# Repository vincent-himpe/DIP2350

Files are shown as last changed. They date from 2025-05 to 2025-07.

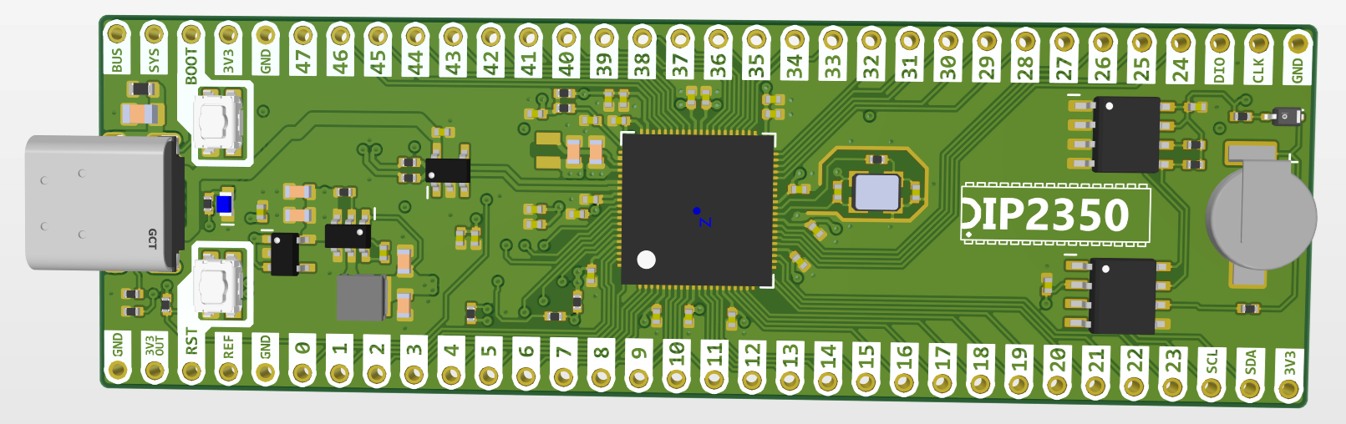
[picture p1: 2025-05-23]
IMAGES/DIP2350-RC2-FRONT.png

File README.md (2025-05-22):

# DIP2350
## An RP2350 Packaged as a 64 pin DIP package that fits a standard 64pin dip socket (motorola MC68000 style)

### Overview

- USB Type-C connector. Right angle , thru hole for mechanical stability. long overhang so you can have this go through an enclosure wall
- USB powered or self powered. self powered up to 12 volt
- ideal diode / or-ing / e-fuse circuit (optional) to prevent backfeeding usb. Current limit on the ideal diode. the circuit can be used as a power or-ing to provide backup power from a Li-Ion cell and charger
- ESD protection on the USB port using TVS diodes
- 3v3 DC/Dc regulator can deliver up to 1A of load current. In this case you need to provide 5v as USB cannot provide source current.
- RP2350B in 80 pin QFN with all 48 GPIO brought out.
- Flash 128Mbit
- optional PSRAM on GPIO47
- optional 3v reference for analog circuitry LM4040-3
- Heartbeat led on gp25 with solder bridge. Can be removed from circuit.
- using abracon XTAL and polarized inductor for 1v1 regulator
- boot and reset button. secondary boot button under usb so you can use a paperclip through the enclosure to force boot.
- on board, optional i2c bus :
- - I2C EEPROM or FRAM
  - I2C RTC with battery backup 1220 cell.
  - - cheap version using an M41t11
    - precision using a MEMS DS3231. option to use brown-out detection to hold cpu in reset till power stabilizes. optional interrupt on GPIO21. User needs to wire the i2c bus to desired io port.
- 4 layer board with controlled impedance and power planes. Board designed so it can be made at OshPark, JLCPCB or PCBway
- CAD source available under Creative Commons ZERO . Public Domain License. Altium Format. 
- Production pack (gerber/drill/bom available.
- BOM is procurable from Digikey/Mouser as well as LCSC (Asia) with direct LCSC order codes if you want his to be partially assembled by JLCPCB.
- pinheaders to be used are the turned pin type. Not the square Dupont style that destroys breadboards and ic sockets. Preci-Dip or equivalent.

DIP2350 FRONT

DIP2350 BACK

## Schematic

[DIP2350 SCHEMATIC - RC0.pdf](https://github.com/user-attachments/files/20359181/DIP2350.SCHEMATIC.-.RC0.pdf)

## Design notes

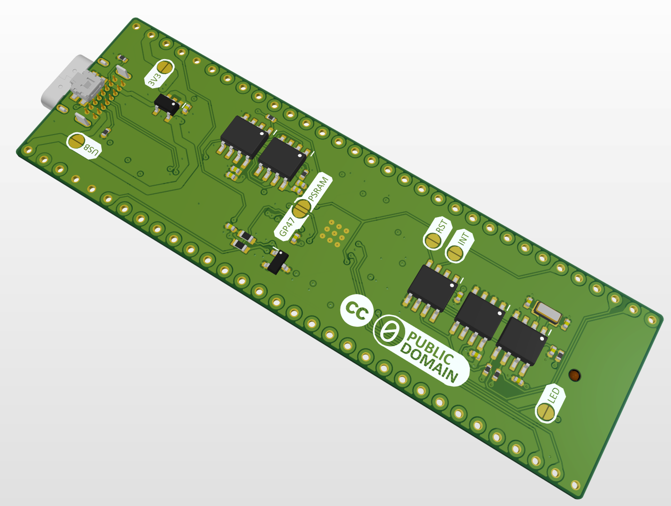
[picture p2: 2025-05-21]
IMAGES/DIP2350-BACK.png

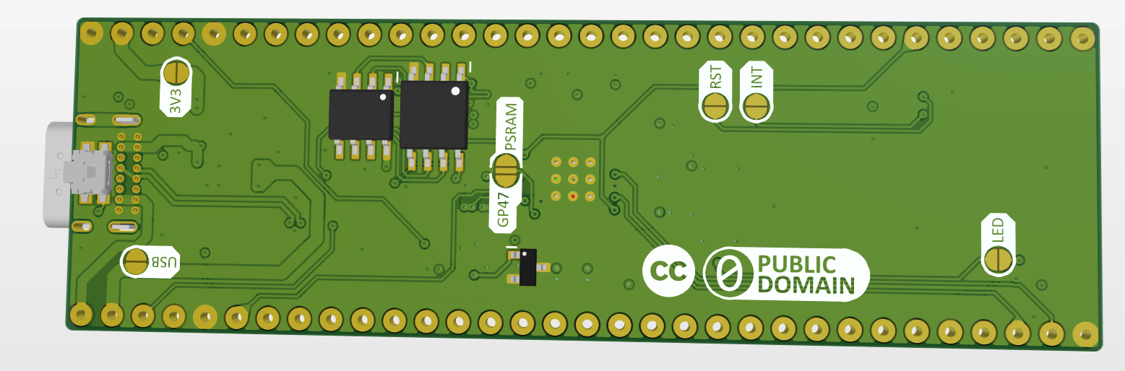
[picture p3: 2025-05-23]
IMAGES/DIP2350-RC2-BACK.png

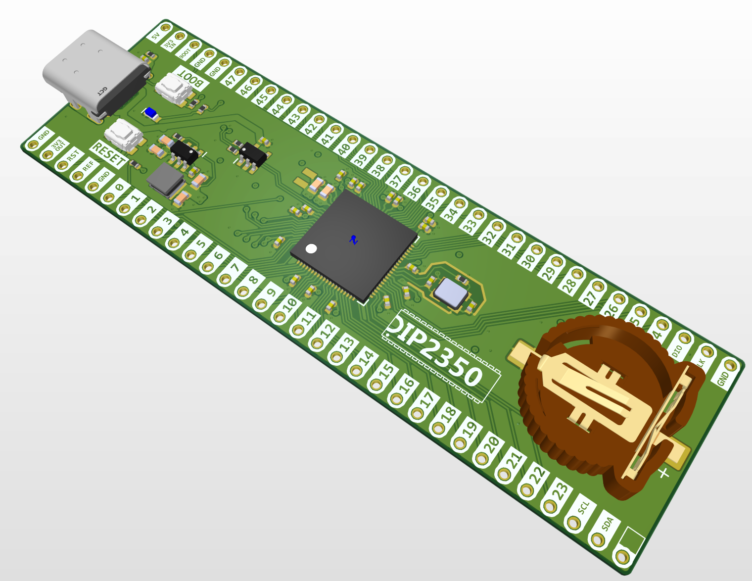
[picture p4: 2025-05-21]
IMAGES/DIP2350-FRONT.png

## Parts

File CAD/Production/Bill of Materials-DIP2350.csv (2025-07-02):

Description | Designator | Quantity | LCSC
CAPACITOR,CERAMIC,22uF,16V,X5R,0603 | C1, C2, C4, C5 | 4 | C2762594
CAPACITOR,CERAMIC,100nF,16V,X7R,0402 | C3, C6, C7, C8, C9, C10, C12, C13, C14, C15, C16, C18, C20, C22, C27, C28, C32, C34, C35, C39 | 20 | C60474
CAPACITOR,CERAMIC,4u7,10V,X5R,0402, CAPACITOR,CERAMIC,4u7,10V,X5R,0603 | C11, C17, C19, C21, C23, C24, C29, C30, C31, C40 | 10 | C1705
CAPACITOR,CERAMIC,15pF,50V,C0G,0402 | C25, C26 | 2 | C3906764
CAPACITOR,CERAMIC,10nF,200V,X7R,0805 (2012),ESD | C33 | 1 | C36911368
DIODE,TVS,DUAL,UNIDIRECTIONAL,USB | D1 | 1 | C22358704
LED,BLUE,0603 | D2 | 1 | C965807
DIODE,75V,215mA,SOD323,LOW LEAKAGE | D3, D4 | 2 | C459842
CONN,USB-C,16P,RA,TH,8.94X9.17 | J1 | 1 | C36936564
CONN,1X3,1MM,RA,SMD,JST,SM03B | J7 | 1 | C160403
BAT,3V,SMD,SEIKO MS621R | K1 | 1
IND,4.7uH,1.06A,3X3, NRH3012T4R7MN | L1 | 1 | C5159666
IND,3U3,RP2350, ABRACON AOTA-B201610S3R3-101-T | L2 | 1 | C42411119
RESISTOR,1K,1%,63mW,0402 (1005) | R1, R6, R7, R10, R17, R18, R19 | 7 | C106235
RESISTOR,5K1,1%,63mW,0402 (1005) | R2, R3 | 2 | C105872
RESISTOR,27R,1%,63mW,0402 (1005) | R4, R5 | 2 | C138021
RESISTOR,10K,1%,63mW,0402 (1005) | R8, R9, R14 | 3 | C60490
RESISTOR,33R,1%,63mW,0402 (1005) | R11, R16 | 2 | C138002
RESISTOR,4K7,1%,63mW,0402 (1005) | R12, R13 | 2 | C105871
RESISTOR,1M,1%,100mW,0603 (1608) | R15 | 1 | C105578
SW,SMD,TACT,4PIN,2.9X3.5,4PIN,SIDE ACTUATOR | SW1 | 1 | C483790
SW,SMD,TACT,4PIN,2.9X3.5,4PIN | SW2, SW3 | 2 | C483888
IC,CPU,RP2350B,QFN80 | U1 | 1 | C42415655
IC,PMIC,STEP-DOWN, 2A 3.3V | U2 | 1 | C780769
IC,FLASH,QSPI,16Mx8 | U3 | 1 | C97521
IC,VOLTAGE REFERENCE,3.0V | U4 | 1 | C460608
IC,PSRAM,QSPI,8Mx8,SO8 | U5 | 1 | C5333729
IC,FRAM,I2C, 64KBIT | U6 | 1 | C914923
IC,RTC,I2C,DS3231M | U8 | 1 | C107410
IC,PMIC,IDEAL DIODE ORING CONTROLLER | U9 | 1 | C3235547
XTAL,12MHZ,RP2350 | X1 | 1 | C20625731

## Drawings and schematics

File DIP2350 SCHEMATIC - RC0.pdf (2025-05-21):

R2 | 0402
R10 | 0402

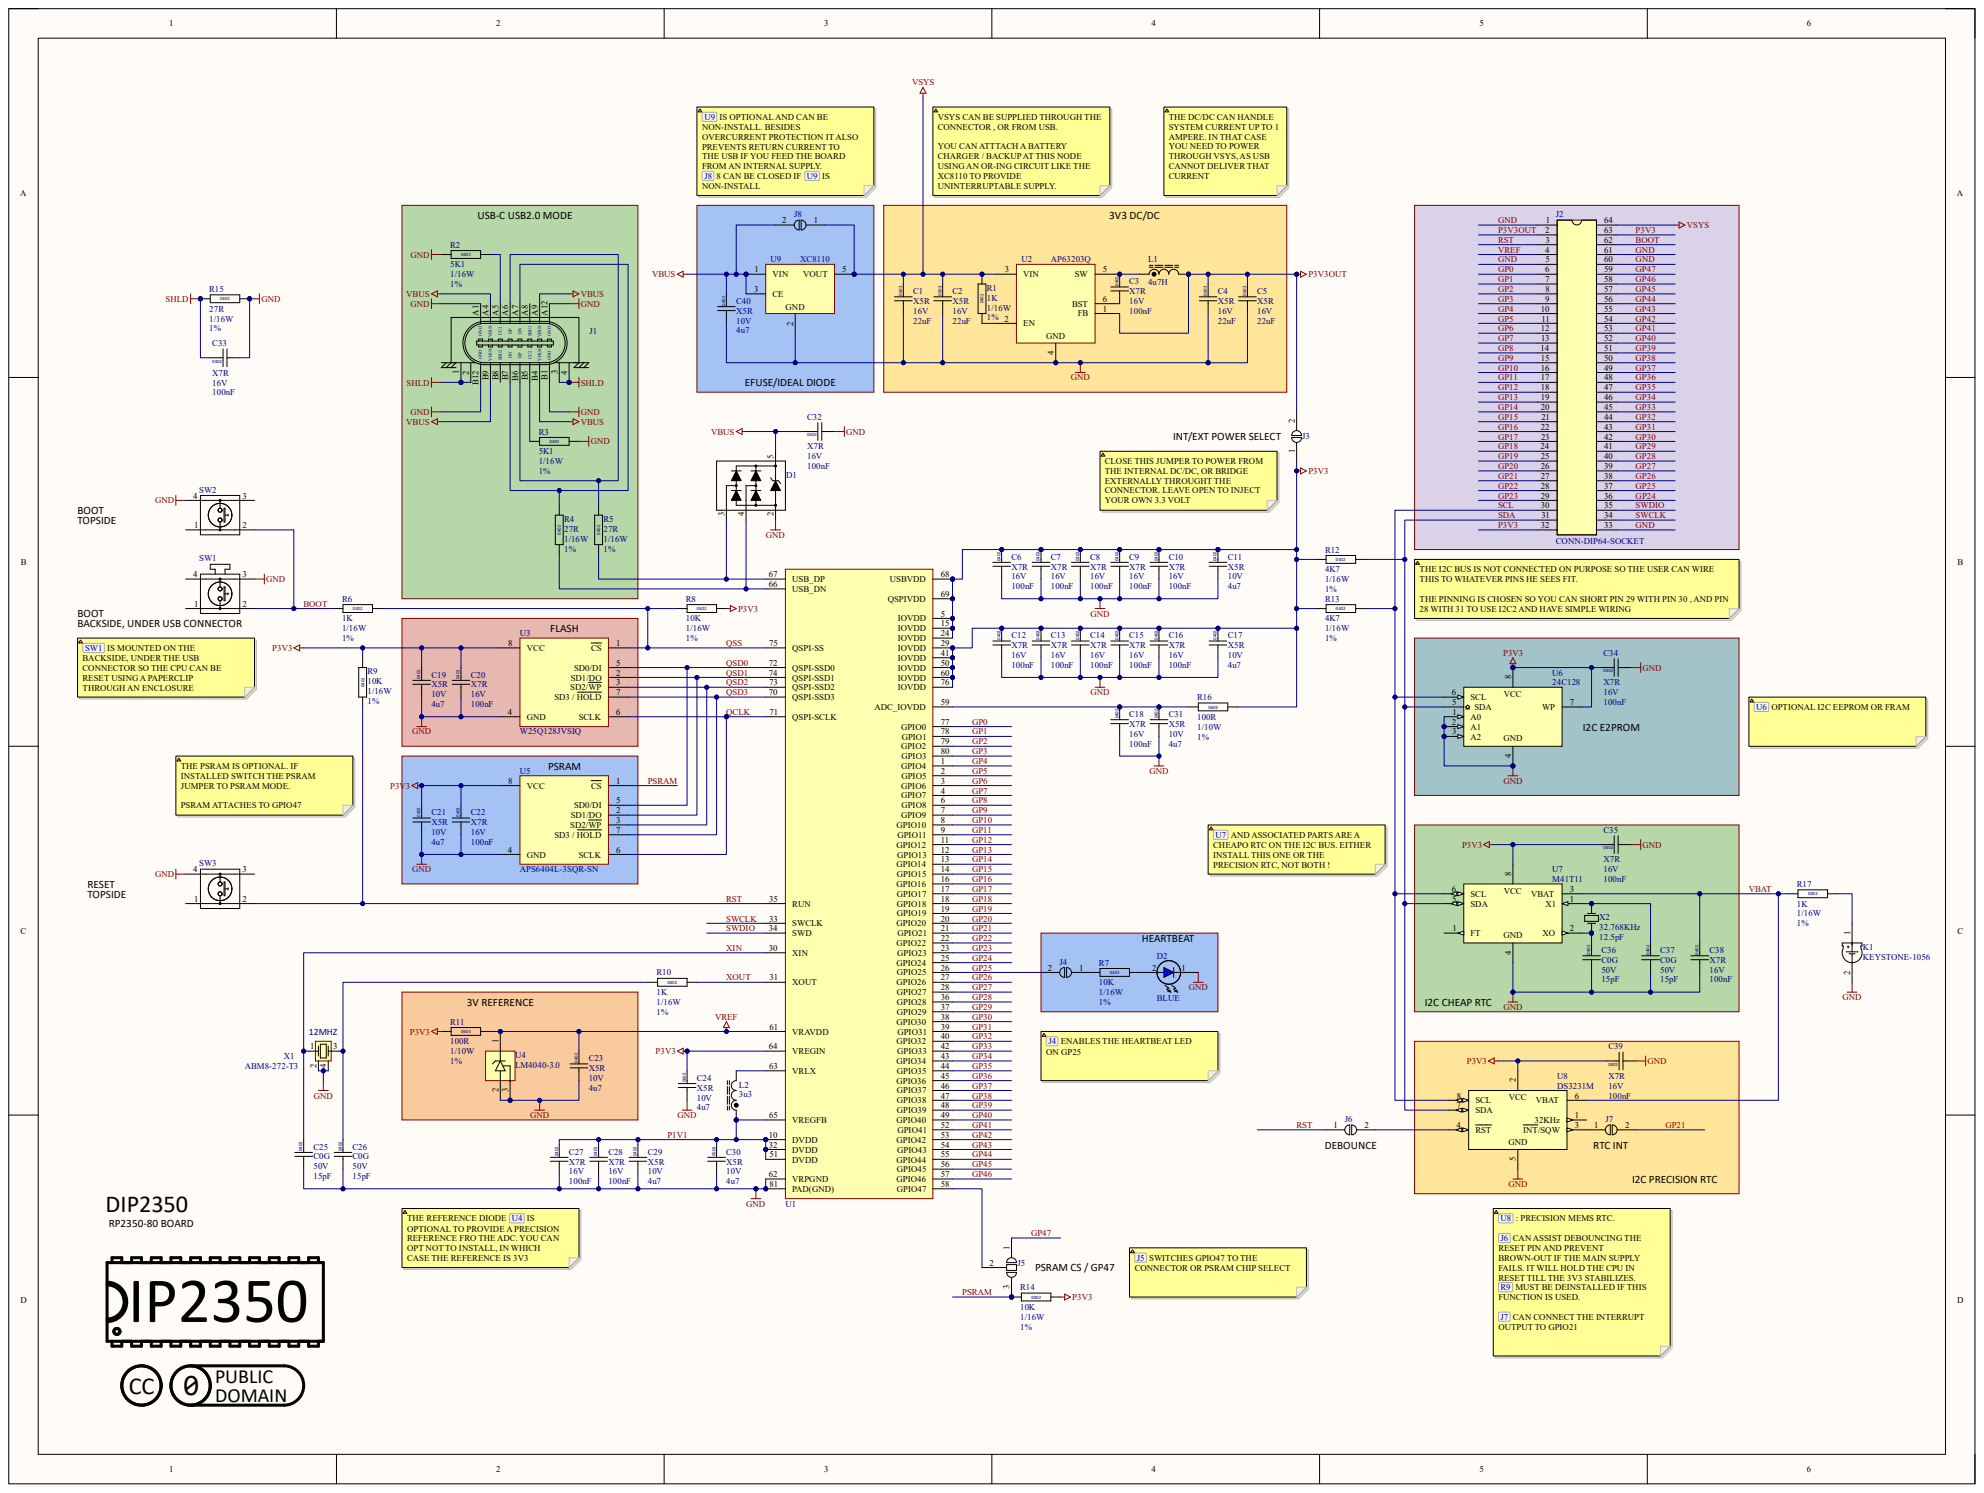
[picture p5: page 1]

U9 IS OPTIONAL AND CAN BE
NON-INSTALL. BESIDES
OVERCURRENT PROTECTION IT ALSO
PREVENTS RETURN CURRENT TO
THE USB IF YOU FEED THE BOARD
FROM AN INTERNAL SUPPLY.
J8 8 CAN BE CLOSED IF U9 IS
NON-INSTALL

VSYS CAN BE SUPPLIED THROUGH THE
CONNECTOR , OR FROM USB.

THE DC/DC CAN HANDLE
SYSTEM CURRENT UP TO 1
AMPERE. IN THAT CASE
YOU NEED TO POWER
THROUGH VSYS, AS USB
CANNOT DELIVER THAT
CURRENT

YOU CAN ATTTACH A BATTERY
CHARGER / BACKUP AT THIS NODE
USING AN OR-ING CIRCUIT LIKE THE
XC8110 TO PROVIDE
UNINTERRUPTABLE SUPPLY.

INT/EXT POWER SELECT

CLOSE THIS JUMPER TO POWER FROM
THE INTERNAL DC/DC, OR BRIDGE
EXTERNALLY THROUGHT THE
CONNECTOR. LEAVE OPEN TO INJECT
YOUR OWN 3.3 VOLT

THE I2C BUS IS NOT CONNECTED ON PURPOSE SO THE USER CAN WIRE
THIS TO WHATEVER PINS HE SEES FIT.

BOOT
BACKSIDE, UNDER USB CONNECTOR

THE PINNING IS CHOSEN SO YOU CAN SHORT PIN 29 WITH PIN 30 , AND PIN
28 WITH 31 TO USE I2C2 AND HAVE SIMPLE WIRING

SW1 IS MOUNTED ON THE
BACKSIDE, UNDER THE USB
CONNECTOR SO THE CPU CAN BE
RESET USING A PAPERCLIP
THROUGH AN ENCLOSURE

U6 OPTIONAL I2C EEPROM OR FRAM

THE PSRAM IS OPTIONAL. IF
INSTALLED SWITCH THE PSRAM
JUMPER TO PSRAM MODE.

U7 AND ASSOCIATED PARTS ARE A
CHEAPO RTC ON THE I2C BUS. EITHER
INSTALL THIS ONE OR THE
PRECISION RTC, NOT BOTH !

J4 ENABLES THE HEARTBEAT LED

THE REFERENCE DIODE U4 IS
OPTIONAL TO PROVIDE A PRECISION
REFERENCE FRO THE ADC. YOU CAN
OPT NOT TO INSTALL, IN WHICH
CASE THE REFERENCE IS 3V3

J6 CAN ASSIST DEBOUNCING THE
RESET PIN AND PREVENT
BROWN-OUT IF THE MAIN SUPPLY
FAILS. IT WILL HOLD THE CPU IN
RESET TILL THE 3V3 STABILIZES.
R9 MUST BE DEINSTALLED IF THIS
FUNCTION IS USED.

J5 SWITCHES GPIO47 TO THE
CONNECTOR OR PSRAM CHIP SELECT

J7 CAN CONNECT THE INTERRUPT
OUTPUT TO GPIO21

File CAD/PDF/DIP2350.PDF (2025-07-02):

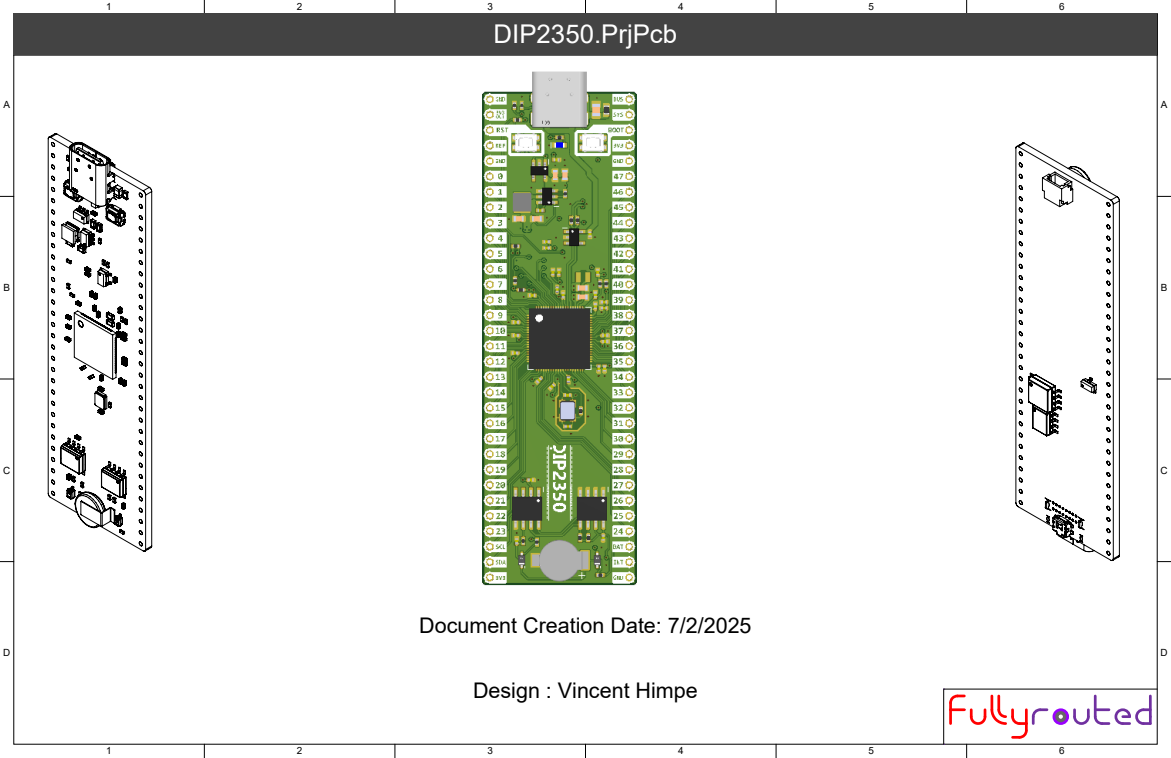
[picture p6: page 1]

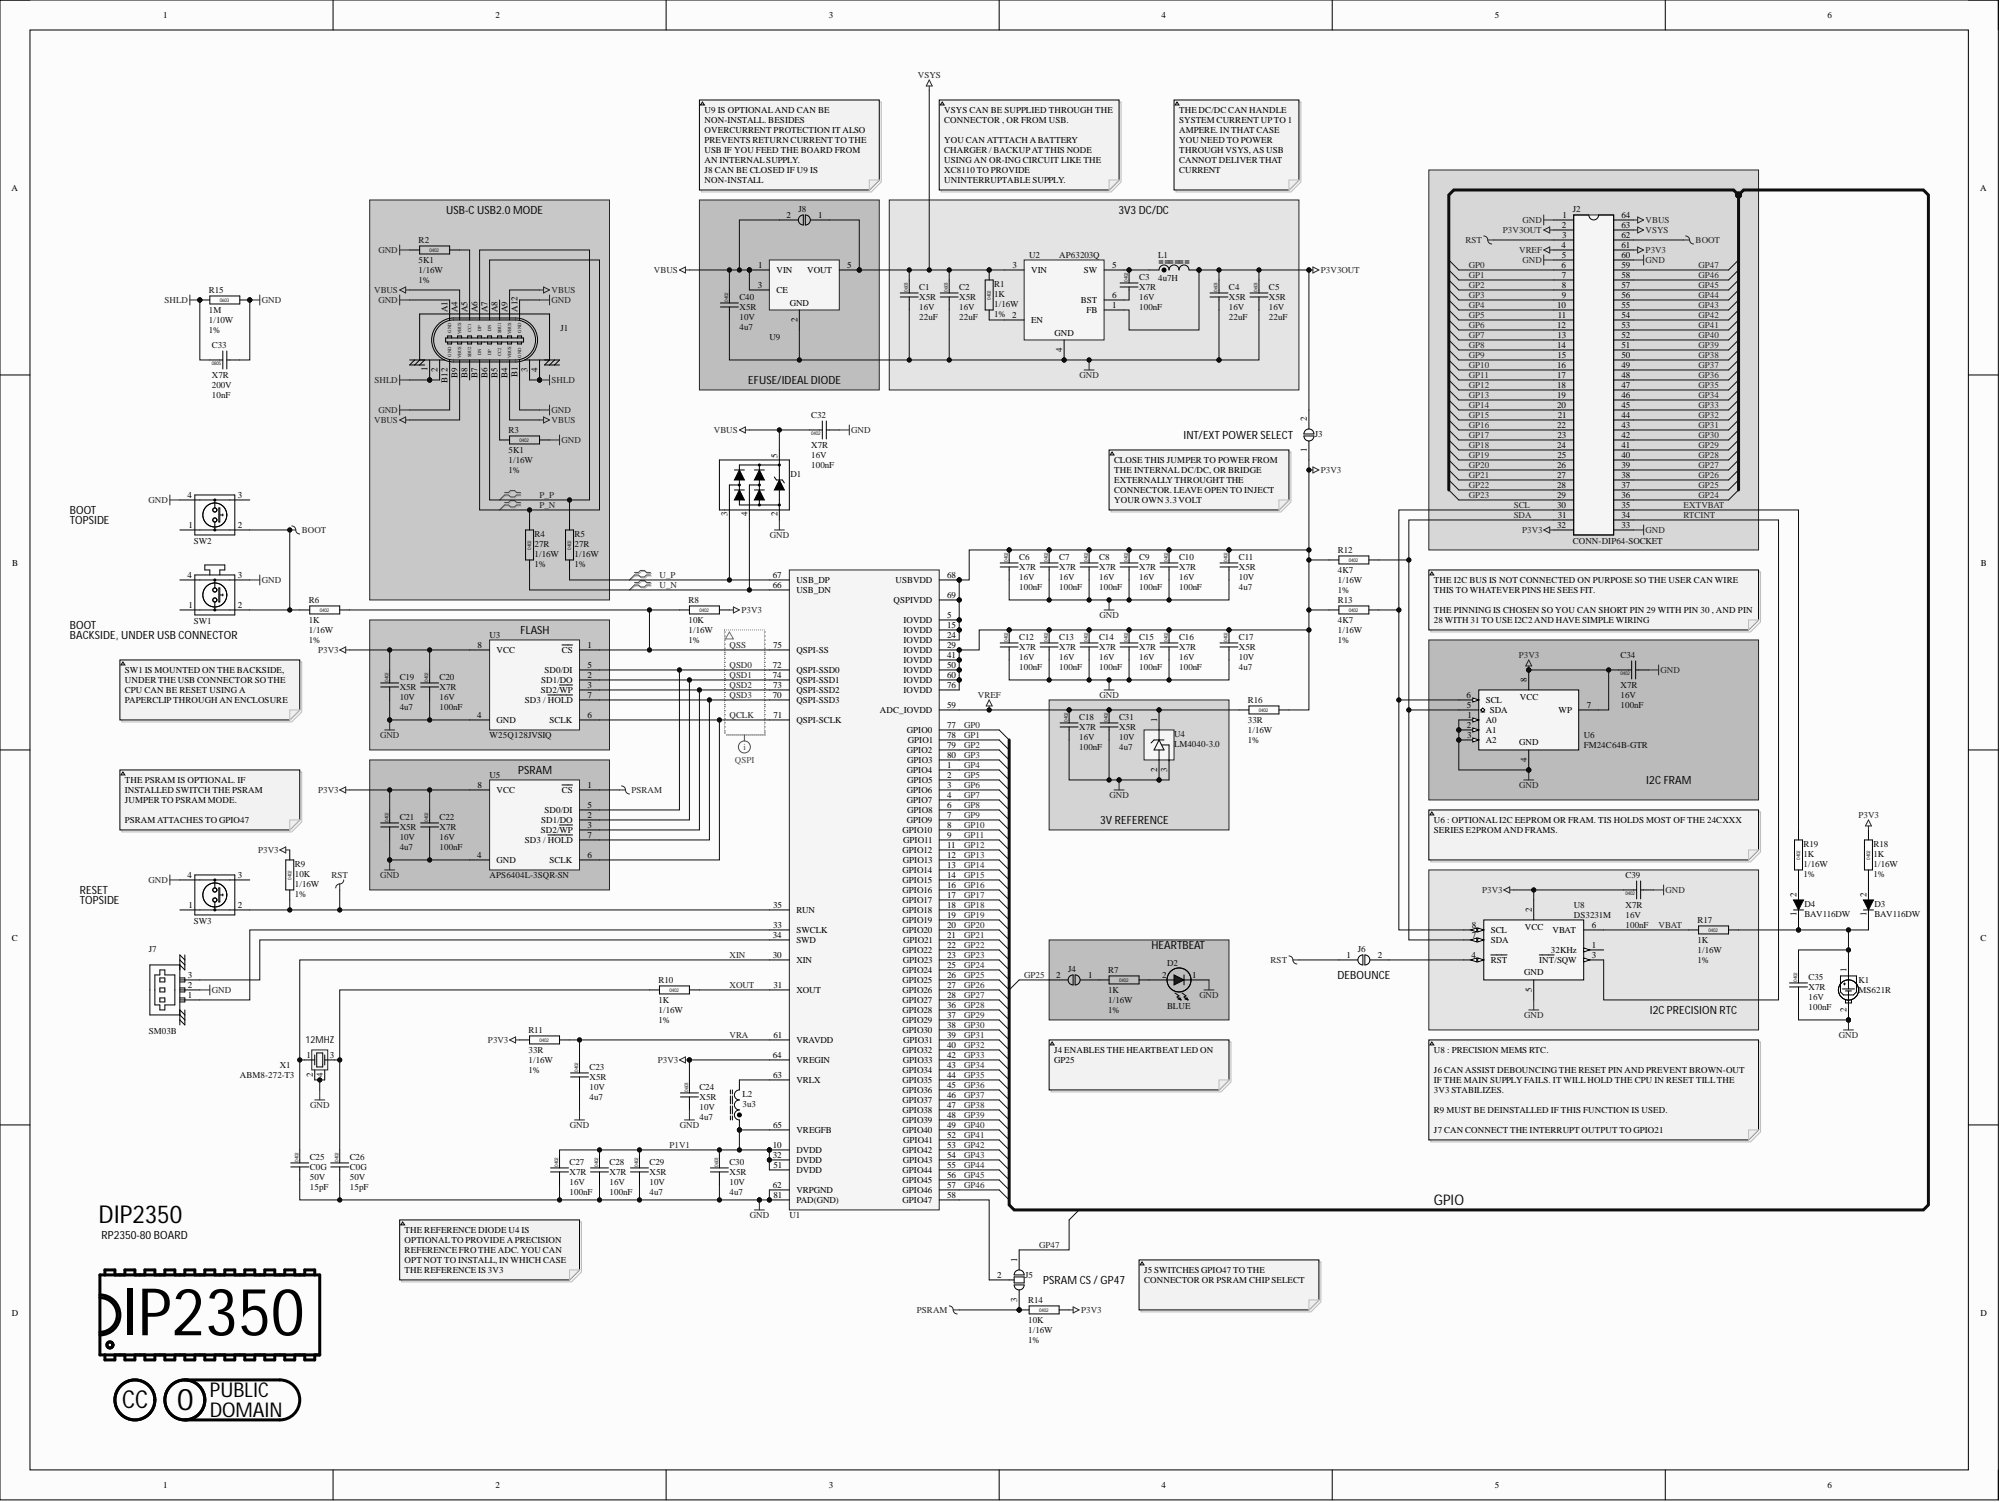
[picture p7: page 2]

3 | QSD 2 | 7 3 | | 7 6 | G N
7 | | QSD 3 | 7 0

3 | 8 0
7 | 9 GP1 1
6 | 1 1 GP1 2

1 0
3 2

OR PSRAM CHIP SE

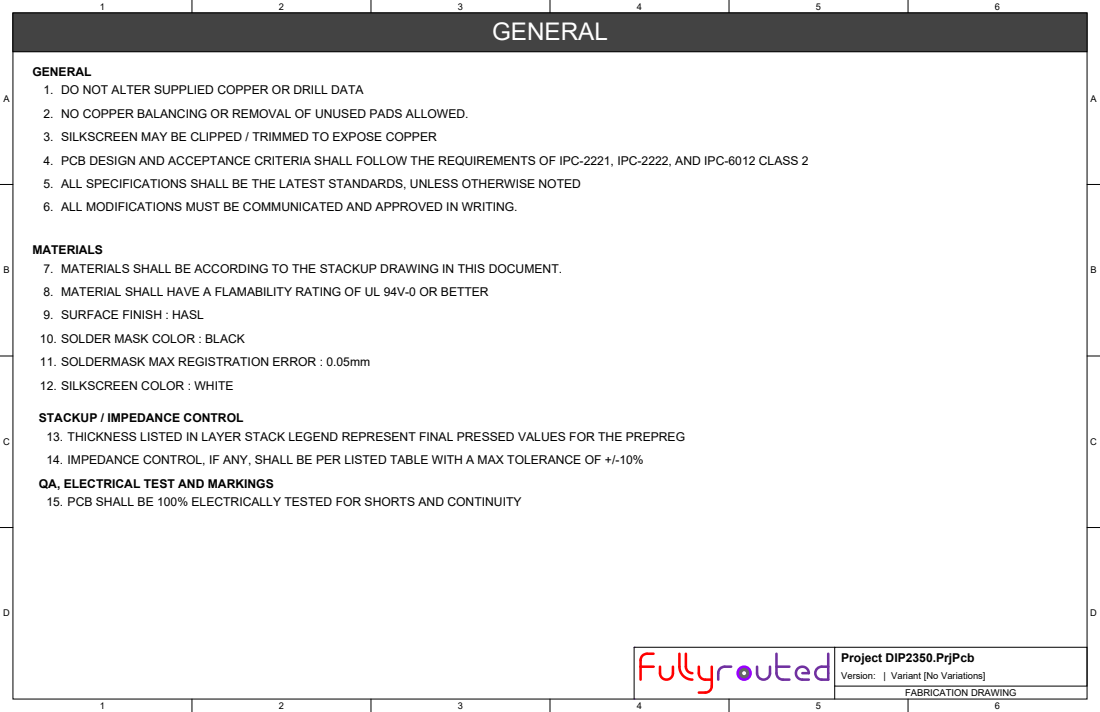
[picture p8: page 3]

GENERAL
1. DO NOT ALTER SUPPLIED COPPER OR DRILL DATA
2. NO COPPER BALANCING OR REMOVAL OF UNUSED PADS ALLOWED.
3. SILKSCREEN MAY BE CLIPPED / TRIMMED TO EXPOSE COPPER
4. PCB DESIGN AND ACCEPTANCE CRITERIA SHALL FOLLOW THE REQUIREMENTS OF IPC-2221, IPC-2222, AND IPC-6012 CLASS 2
5. ALL SPECIFICATIONS SHALL BE THE LATEST STANDARDS, UNLESS OTHERWISE NOTED
6. ALL MODIFICATIONS MUST BE COMMUNICATED AND APPROVED IN WRITING.

MATERIALS
7. MATERIALS SHALL BE ACCORDING TO THE STACKUP DRAWING IN THIS DOCUMENT.
8. MATERIAL SHALL HAVE A FLAMABILITY RATING OF UL 94V-0 OR BETTER
9. SURFACE FINISH : HASL
10. SOLDER MASK COLOR : BLACK
11. SOLDERMASK MAX REGISTRATION ERROR : 0.05mm
12. SILKSCREEN COLOR : WHITE

STACKUP / IMPEDANCE CONTROL
13. THICKNESS LISTED IN LAYER STACK LEGEND REPRESENT FINAL PRESSED VALUES FOR THE PREPREG
14. IMPEDANCE CONTROL, IF ANY, SHALL BE PER LISTED TABLE WITH A MAX TOLERANCE OF +/-10%
QA, ELECTRICAL TEST AND MARKINGS
15. PCB SHALL BE 100% ELECTRICALLY TESTED FOR SHORTS AND CONTINUITY

Project DIP2350.PrjPcb
Version: | Variant [No Variations]

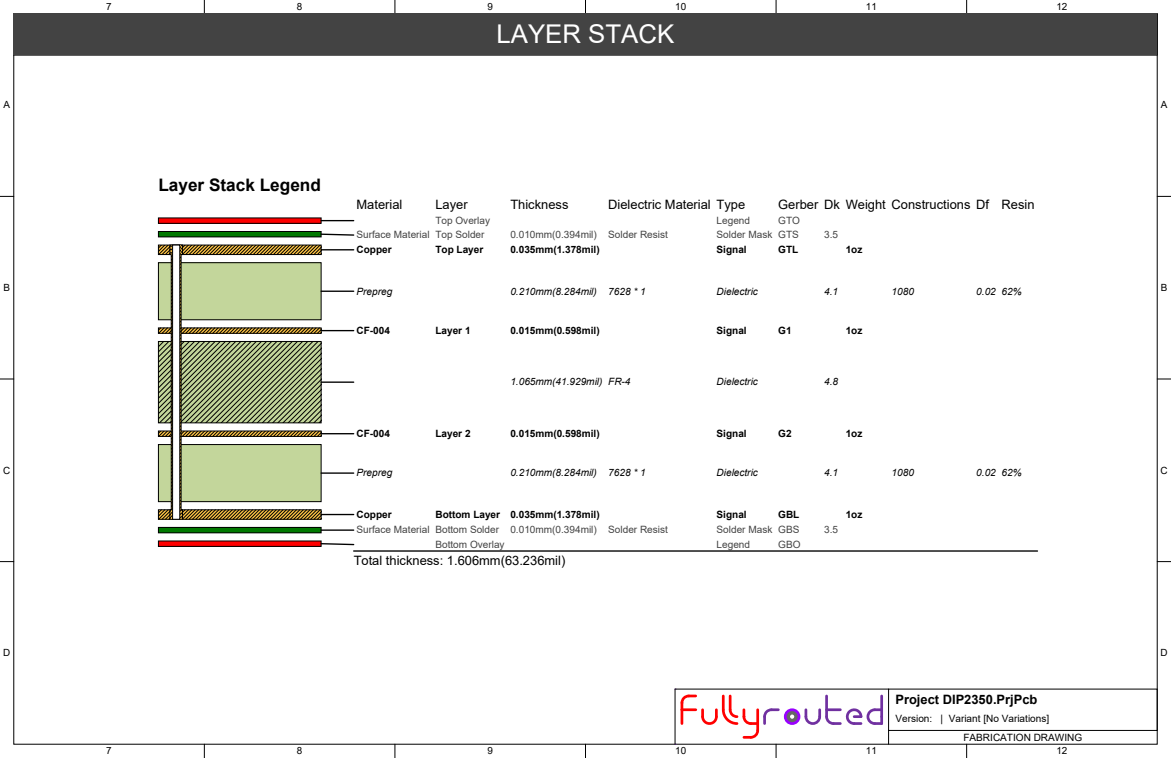
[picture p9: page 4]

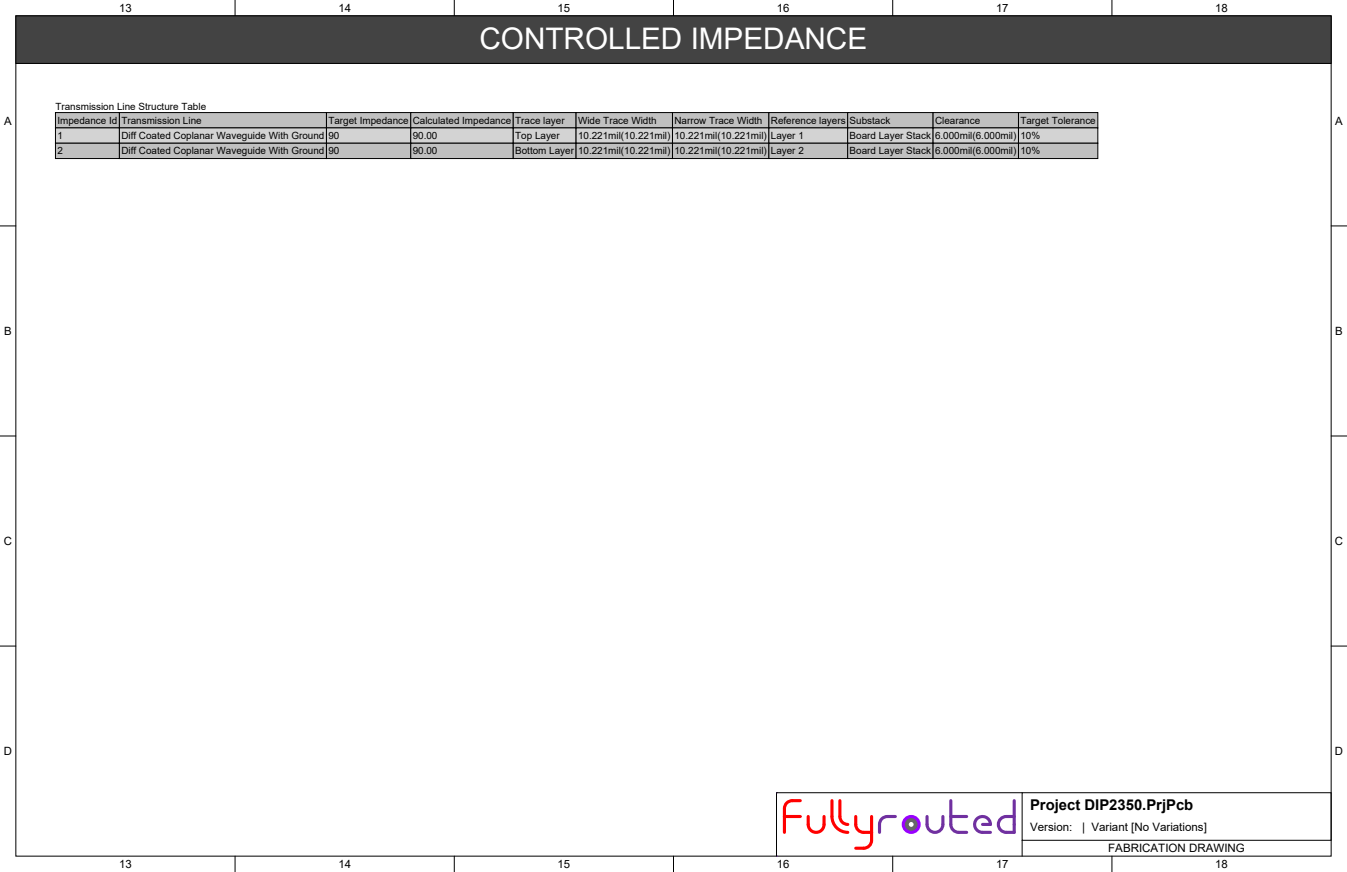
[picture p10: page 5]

Transmission Line Structure Table

Impedance Id | Transmission Line | Target Impedance | Calculated Impedance | Trace layer | Wide Trace Width | Narrow Trace Width | Reference layers | Substack | Clearance | Target Tolerance
1 | Diff Coated Coplanar Waveguide With Ground | 90 | 90.00 | Top Layer | 10.221mil(10.221mil) | 10.221mil(10.221mil) | Layer 1 | Board Layer Stack | 6.000mil(6.000mil) | 10%
2 | Diff Coated Coplanar Waveguide With Ground | 90 | 90.00 | Bottom Layer | 10.221mil(10.221mil) | 10.221mil(10.221mil) | Layer 2 | Board Layer Stack | 6.000mil(6.000mil) | 10%

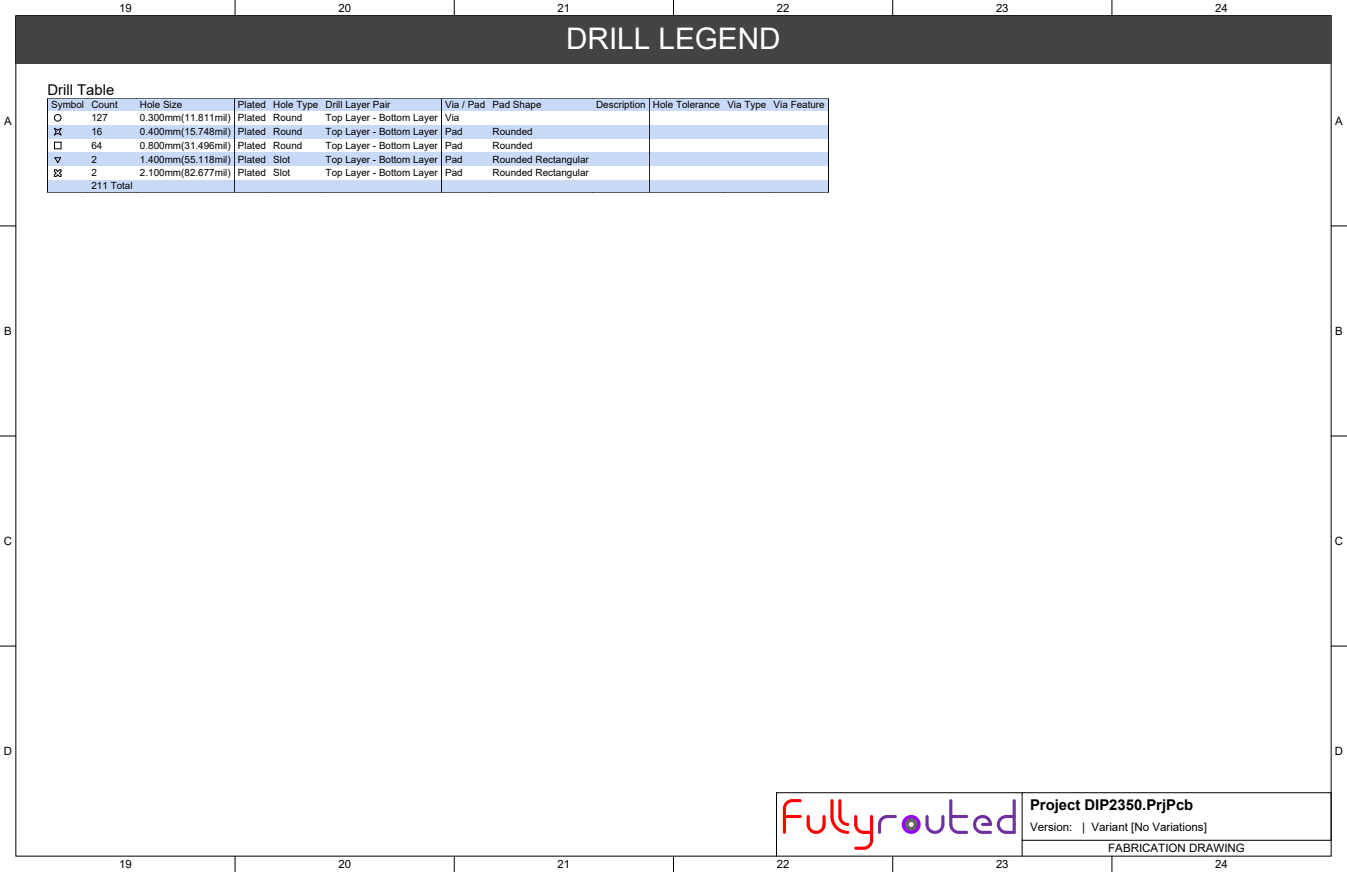
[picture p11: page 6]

Symbol | Count | Hole Size | Plated | Hole Type | Drill Layer Pair | Via / Pad | Pad Shape | Description | Hole Tolerance | Via Type | Via Feature

127 | 0.300mm(11.811mil) | Plated | Round | Top Layer - Bottom Layer | Via
16 | 0.400mm(15.748mil) | Plated | Round | Top Layer - Bottom Layer | Pad | Rounded
64 | 0.800mm(31.496mil) | Plated | Round | Top Layer - Bottom Layer | Pad | Rounded
2 | 1.400mm(55.118mil) | Plated | Slot | Top Layer - Bottom Layer | Pad | Rounded Rectangular
2 | 2.100mm(82.677mil) | Plated | Slot | Top Layer - Bottom Layer | Pad | Rounded Rectangular
211 Total

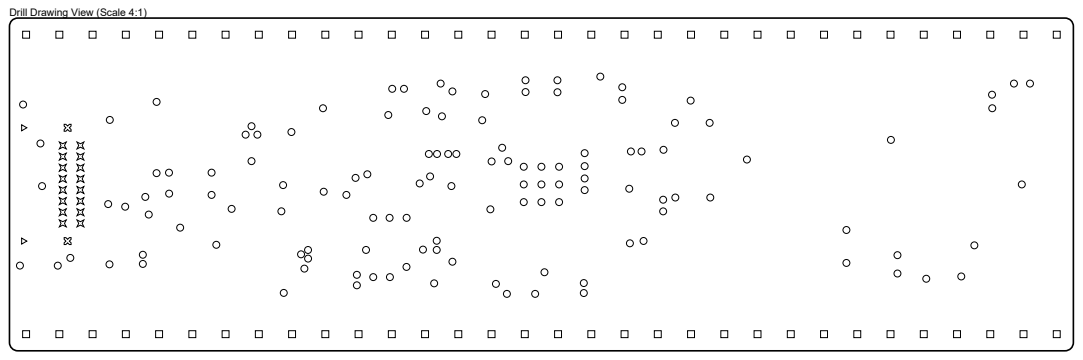
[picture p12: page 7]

Drill Drawing View (Scale 4:1)

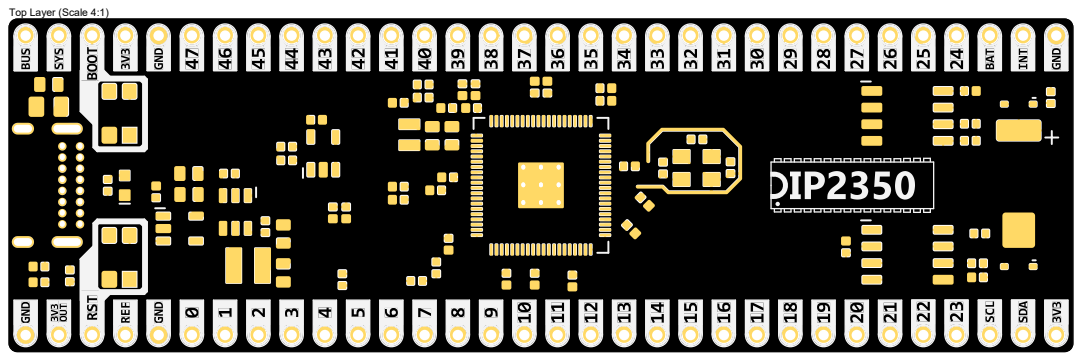
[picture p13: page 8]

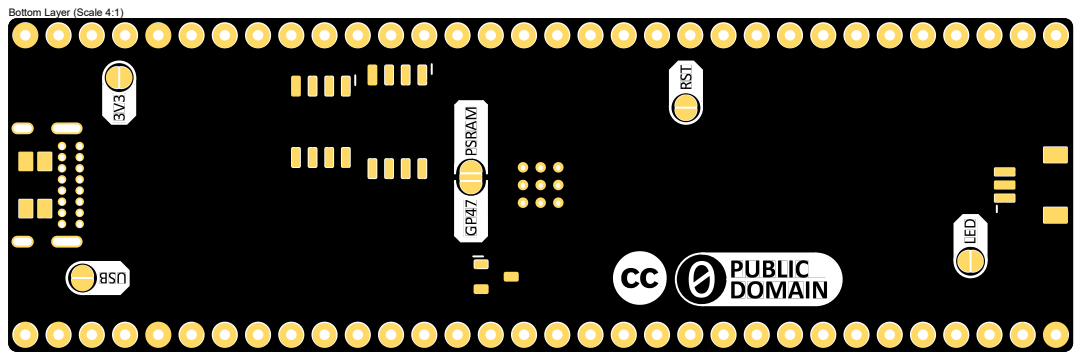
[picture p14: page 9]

LAYER VIEW : TOP LAYER

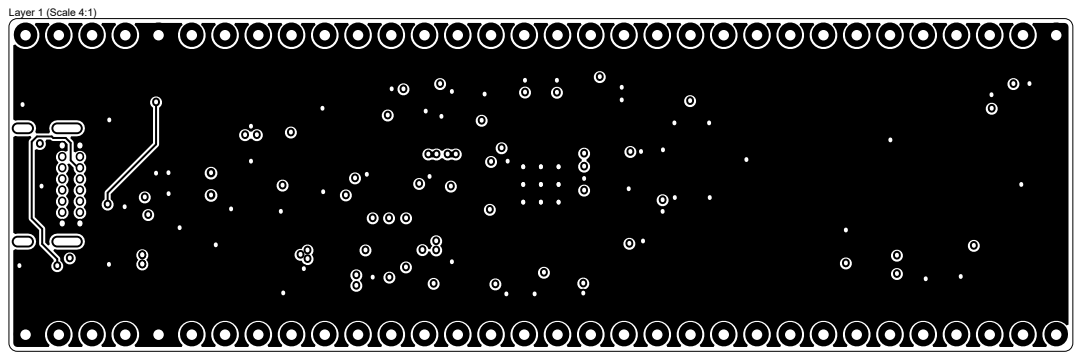
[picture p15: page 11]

LAYER VIEW : MID LAYER 1

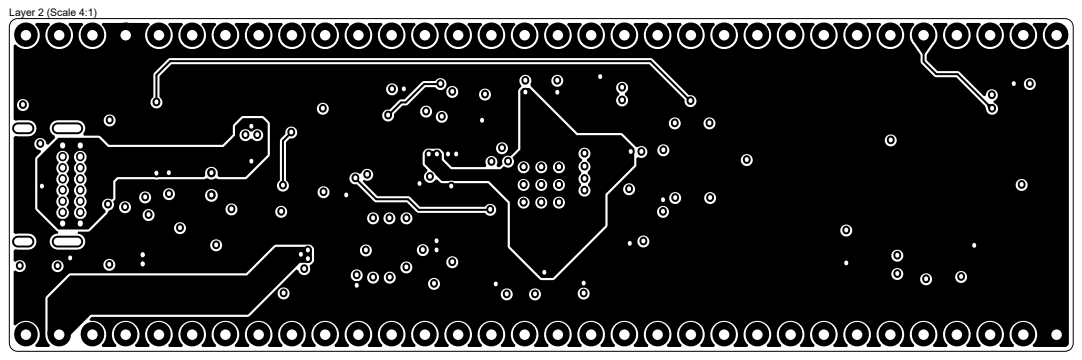
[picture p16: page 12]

LAYER VIEW : MID LAYER 2


LAYER VIEW : BOTTOM LAYER


LAYER VIEW : TOP SOLDER MASK


LAYER VIEW : BOTTOM SOLDER MASK


LAYER VIEW : TOP SILKSCREEN (LEGEND)


LAYER VIEW : BOTTOM SILKSCREEN (LEGEND)


Unless otherwise specified the following rules apply:
1. DO NOT DEVIATE FROM ARTWORK OR BOM WITHOUT PRIOR AUTHORIZATION.
2. ASSEMBLE AND INSPECT PER IPC-610 CLASS 2

Bill of Materials and Material Handling
3. THE BOM CONTAINED IN THIS DOCUMENT IS AS-BUILT. NON-INSTALLED PARTS HAVE BEEN REMOVED. ADDITIONAL BOM FORMATS ARE AVAILABLE IN THE PROJECT FILES
4. ANY PART SUBSTITUTIONS MUST BE APPROVED IN WRITING BEFORE ASSEMBLY
5. ALL MATERIALS MUST BE PROCURED FROM MANUFACTURER AUTHORIZED DISTRIBUTORS OR THE ORIGINAL MANUFACTURER
6. ALL COMPONENTS AND BOARDS TO BE HANDLED AND STORED ACCORDING TO IPC GUIDELINES
7. ESD CONTROL PER IPC RULES

Soldering
8. SOLDERING TO BE DONE USING SN37PB63 ALLOY USING ALLOY MANUFACTURER RECOMMENDED NO-CLEAN FLUX
9. BGA COMPONENTS WITH LEAD-FREE CONNECTIONS NEED TO BE REBALLED WITH SN63PB37. MIXING OF ALLOYS IS NOT PERMITTED.
10. SOLDERING PREFERRABLY TO BE DONE USING NITROGEN ATMOSPHERE
11. SURPLUS COMPONENTS TO VACUUM SEALED WITH DESSICANT IN ANTISTATIC BAGS
12. INCOMING MATERIAL (BOARDS AND COMPONENTS) NEEDS TO BE INSPECTED FOR HUMIDITY AND BAKED IF NEEDED PRIOR TO USE.
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

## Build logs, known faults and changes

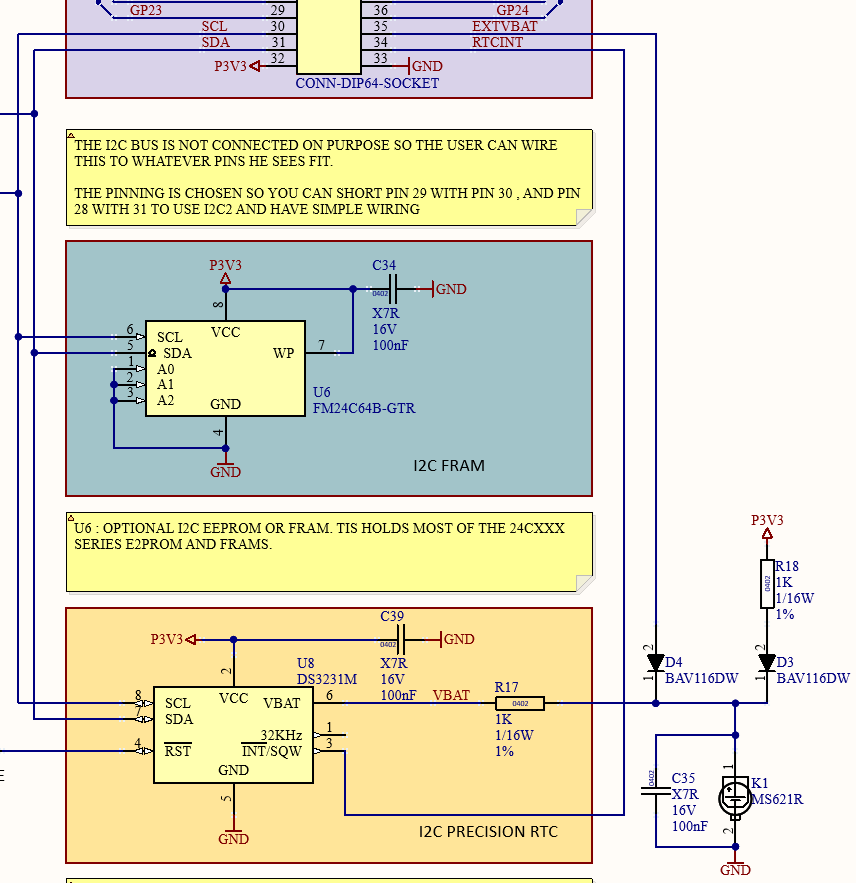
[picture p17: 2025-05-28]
IMAGES/DIP2350-RC3-DEBUG-SCH.png

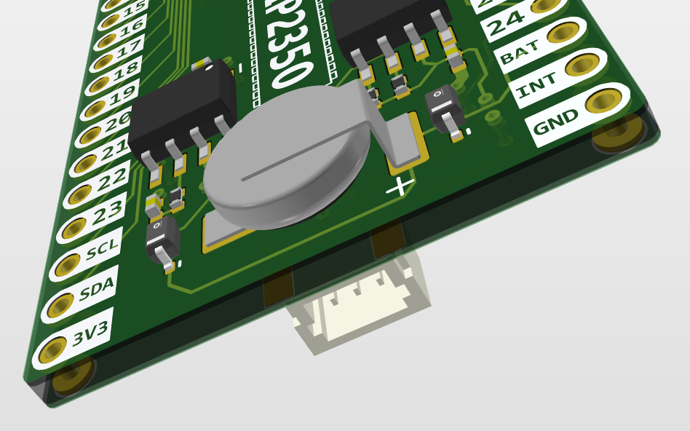
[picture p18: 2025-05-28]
IMAGES/DIP2350-RC3-DEBUG.png
